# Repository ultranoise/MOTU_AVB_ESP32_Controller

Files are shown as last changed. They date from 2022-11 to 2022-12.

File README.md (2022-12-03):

# MOTU_AVB_ESP32_Controller
Building a simple volume controller with a ESP32 for MOTU AVB audio interfaces. Part of the [Ottosonics](https://tamlab.kunstuni-linz.at/projects/ottosonics/) project . 

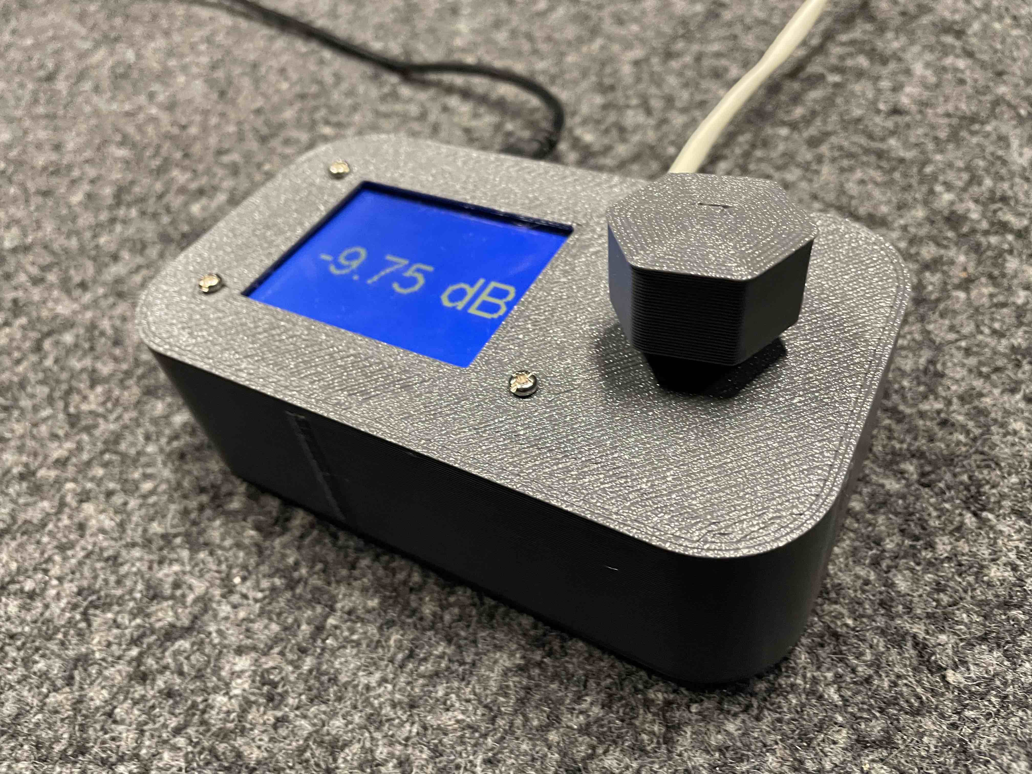
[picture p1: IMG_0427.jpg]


MOTU AVB interfaces have a particular method for receiving HTTP POST messages. First read the MOTU API Reference: 

https://cdn-data.motu.com/downloads/audio/AVB/docs/OSC%20Quick%20Reference.pdf

The principle to GET and POST with MOTU AVB interfaces is rather simple with cURL:

* get the datastore: ``` curl http://192.168.0.5/datastore ``` (use the IP of your interface here)

* read value of mic1 trim: ``` curl http://192.168.0.5/datastore/ext/ibank/0/ch/0/trim ```

* set value of mic1 trim: ``` curl --data 'json={"value":"45"}' http://192.168.0.5/datastore/ext/ibank/0/ch/0/trim ```

* set mixer fader 0 (ch1) value: ``` curl --data 'json={"value":"0.7"}' http://192.168.0.5/datastore/mix/chan/0/matrix/fader ```

* set mixer fader 1 (ch2) value: ``` curl --data 'json={"value":"0.7"}' http://192.168.0.5/datastore/mix/chan/1/matrix/fader ```

* set mixer fader 1 and fader 2 at the same time: ``` curl --data 'json={"0/matrix/fader":"0.2","1/matrix/fader":"0.1"}' http://192.168.0.5/datastore/mix/chan/ ```

# Hardware

We used a ESP32 with ethernet by [Olimex](https://www.olimex.com/Products/IoT/ESP32/ESP32-GATEWAY/open-source-hardware) and a [SPI TFT display](https://www.amazon.de/gp/product/B07YTWRZGR/ref=ppx_yo_dt_b_asin_title_o06_s01?ie=UTF8&psc=1) that we connected as follows:
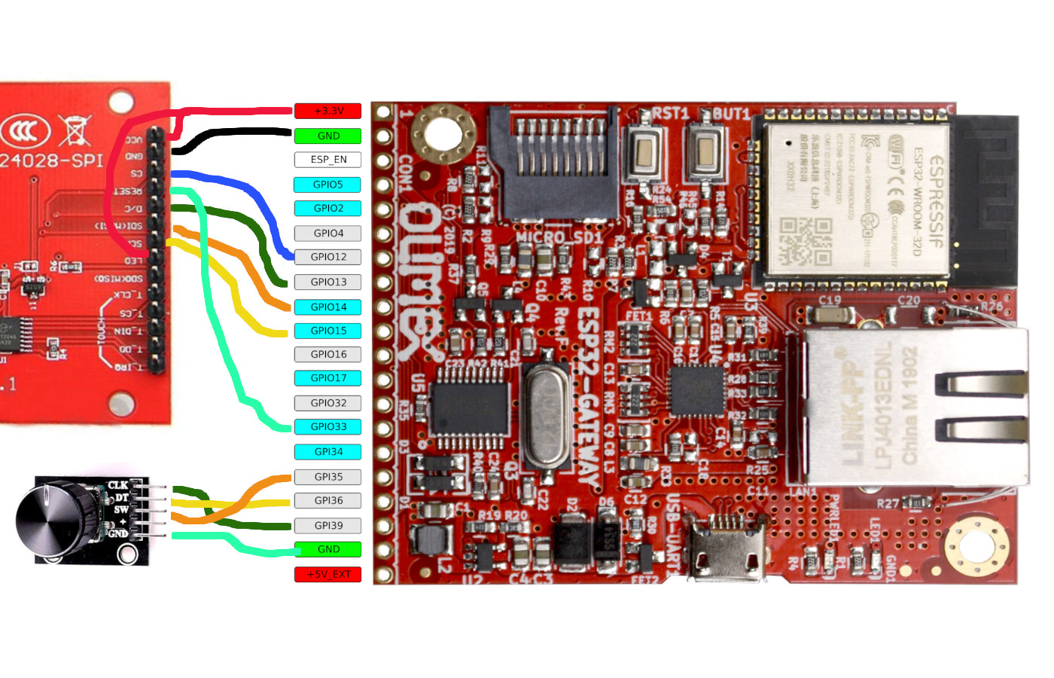
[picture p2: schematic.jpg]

Please note that a WLAN version of this code could be easily implemented with the same board (call wlan functions instead of ethernet). 

# Code

* If you want to download our solution please go to the source folder of this repository

* With our ESP32, the following code can be used to read the datastore:

```
#define ETH_CLK_MODE ETH_CLOCK_GPIO17_OUT
#define ETH_PHY_POWER 5
#include <ETH.h>
#include <HTTPClient.h>

#include <Arduino.h>

#define USE_SERIAL Serial

static bool eth_connected = false;

#include <WiFi.h>
#include <WiFiMulti.h>

WiFiMulti wifiMulti;

void WiFiEvent(WiFiEvent_t event)
{
  switch (event) {
    case ARDUINO_EVENT_ETH_START:
      USE_SERIAL.println("ETH Started");
      //set eth hostname here
      ETH.setHostname("esp32-ethernet");
      break;
    case ARDUINO_EVENT_ETH_CONNECTED:
      USE_SERIAL.println("ETH Connected");
      //eth_connected = true;
      break;
    case ARDUINO_EVENT_ETH_GOT_IP:
      USE_SERIAL.print("ETH MAC: ");
      USE_SERIAL.print(ETH.macAddress());
      USE_SERIAL.print(", IPv4: ");
      USE_SERIAL.print(ETH.localIP());
      if (ETH.fullDuplex()) {
        USE_SERIAL.print(", FULL_DUPLEX");
      }
      USE_SERIAL.print(", ");
      USE_SERIAL.print(ETH.linkSpeed());
      USE_SERIAL.println("Mbps");
      eth_connected = true;
      break;
    case ARDUINO_EVENT_ETH_DISCONNECTED:
      USE_SERIAL.println("ETH Disconnected");
      eth_connected = false;
      break;
    case ARDUINO_EVENT_ETH_STOP:
      USE_SERIAL.println("ETH Stopped");
      eth_connected = false;
      break;
    default:
      break;
  }
}

void testClient(const char * host, uint16_t port)
{
  USE_SERIAL.print("\nconnecting to ");
  USE_SERIAL.println(host);

  WiFiClient client;
  if (!client.connect(host, port)) {
    USE_SERIAL.println("connection failed");
    return;
  }
  client.printf("GET / HTTP/1.1\r\nHost: %s\r\n\r\n", host);
  while (client.connected() && !client.available());
  while (client.available()) {
    USE_SERIAL.write(client.read());
  }

  USE_SERIAL.println("closing connection\n");
  client.stop();
}

void testAvb(const char * host, uint16_t port)
{
  HTTPClient http;

        USE_SERIAL.print("[HTTP] begin...\n");
        // configure traged server and url
        http.begin("http://192.168.0.5/datastore/"); //HTTP
        
        USE_SERIAL.print("[HTTP] GET...\n");
        // start connection and send HTTP header
        int httpCode = http.GET();

        // httpCode will be negative on error
        if(httpCode > 0) {
            // HTTP header has been send and Server response header has been handled
            USE_SERIAL.printf("[HTTP] GET... code: %d\n", httpCode);

            // file found at server
            if(httpCode == HTTP_CODE_OK) {
                String payload = http.getString();
                USE_SERIAL.println(payload);
            }
        } else {
            USE_SERIAL.printf("[HTTP] GET... failed, error: %s\n", http.errorToString(httpCode).c_str());
        }

        http.end();
}

void setup()
{
  USE_SERIAL.begin(115200);
  WiFi.onEvent(WiFiEvent);
  ETH.begin();
}

void loop()
{
  if (eth_connected) {
    testAvb("google.com", 80);
  }
  delay(10000);
}
```

* The issues begin when you try to POST messages. The logic of posting with JSON encoding doesn't work. If you typically use the following code you will get an error:

```

void postDataToServer() {

    HTTPClient http;

    http.begin("http://192.168.0.5/datastore/ext/obank/2/ch/0/name");
    
    http.addHeader("Content-Type", "application/json");
    
    int httpResponseCode = http.POST("{\"value\":\"My favorite channel\"}");
    
    if (httpResponseCode > 0) {

      String response = http.getString();

      Serial.println(httpResponseCode);
      Serial.println(response);

    } else {

      Serial.print("Error on sending PUT Request: ");
      Serial.println(httpResponseCode);

    }

    http.end();
     
}
```

you get a (-5) or (-1) error:

```
ETH Connected
 POSTing to Server...
-5

```
 
So clearly there is a difference in how headers or formatting are set. I used the online service httpbin.org to debug the messages. Basically httpbin.org replied me a copy of what we have to send.  
  
This is what you get if you use the cURL command which works with the MOTU:

```
curl --data 'json={"value":"My favorite channel"}' https://httpbin.org/post  
{
  "args": {}, 
  "data": "", 
  "files": {}, 
  "form": {
    "json": "{\"value\":\"My favorite channel\"}"
  }, 
  "headers": {
    "Accept": "*/*", 
    "Content-Length": "36", 
    "Content-Type": "application/x-www-form-urlencoded", 
    "Host": "httpbin.org", 
    "User-Agent": "curl/7.64.1", 
    "X-Amzn-Trace-Id": "Root=1-62a2ec58-01489dc01c52f8201f03eccb"
  }, 
  "json": null, 
  "origin": "188.23.136.201", 
  "url": "https://httpbin.org/post"
}
```

However, with the previous Arduino code (which doesn't work with the MOTU interface)

```
200
{
  "args": {}, 
  "data": "{\"value\":\"My favorite channel\"}", 
  "files": {}, 
  "form": {}, 
  "headers": {
    "Accept-Encoding": "identity;q=1,chunked;q=0.1,*;q=0", 
    "Content-Length": "31", 
    "Content-Type": "application/json", 
    "Host": "httpbin.org", 
    "User-Agent": "ESP32HTTPClient", 
    "X-Amzn-Trace-Id": "Root=1-62a2e98e-0825a5fe531b2c493b88287d"
  }, 
  "json": {
    "value": "My favorite channel"
  }, 
  "origin": "188.23.136.201", 
  "url": "https://httpbin.org/post"
}

```

Ergo-> there are quite noticeable differences!!

If we use the same arduino code with a different header ("application/x-www-form-urlencoded") instead of (application/json")

```
//http.addHeader("Content-Type", "application/json");
http.addHeader("Content-Type", "application/x-www-form-urlencoded");
```

We get 

```
200
{
  "args": {}, 
  "data": "", 
  "files": {}, 
  "form": {
    "{\"value\":\"My favorite channel\"}": ""
  }, 
  "headers": {
    "Accept-Encoding": "identity;q=1,chunked;q=0.1,*;q=0", 
    "Content-Length": "31", 
    "Content-Type": "application/x-www-form-urlencoded", 
    "Host": "httpbin.org", 
    "User-Agent": "ESP32HTTPClient", 
    "X-Amzn-Trace-Id": "Root=1-62a2ee48-42acf6c158c472cf4e3d67b8"
  }, 
  "json": null, 
  "origin": "188.23.136.201", 
  "url": "https://httpbin.org/post"
}
```

Which looks better, but to accommondate the format that the MOTU interface expects ( json={} ) this is the final code which finally works:

```
void postDataToServerTwo() {
    HTTPClient http;

    http.begin("http://192.168.0.5/datastore/mix/chan/0/matrix/fader"); 
    
    http.addHeader("Content-Type", "application/x-www-form-urlencoded");
    
    int httpResponseCode = http.POST("json={\"value\":\"0.7\"}"); 

    if (httpResponseCode > 0) {

      String response = http.getString();

      Serial.println(httpResponseCode);
      Serial.println(response);

    } else {

      Serial.print("Error on sending PUT Request: ");
      Serial.println(httpResponseCode);

    }

    http.end();
}
```

This simple produces a "204" response and moves the fader!

You can take a look at a complete example in the src folder.

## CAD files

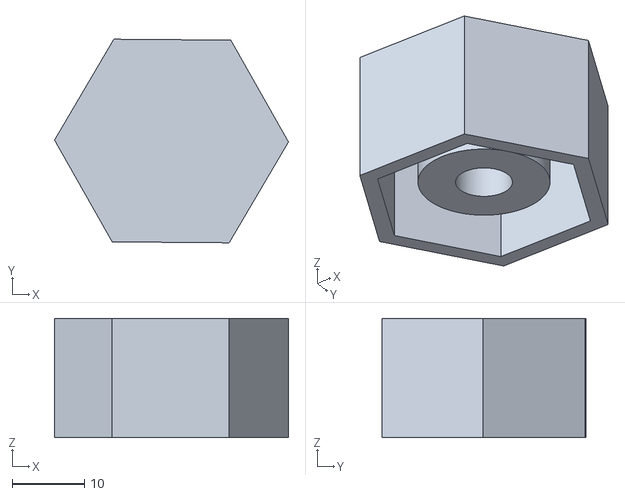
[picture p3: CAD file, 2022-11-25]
3dprint/OTTOsonics volume control knob.stl
32.3 x 28.1 x 16.5

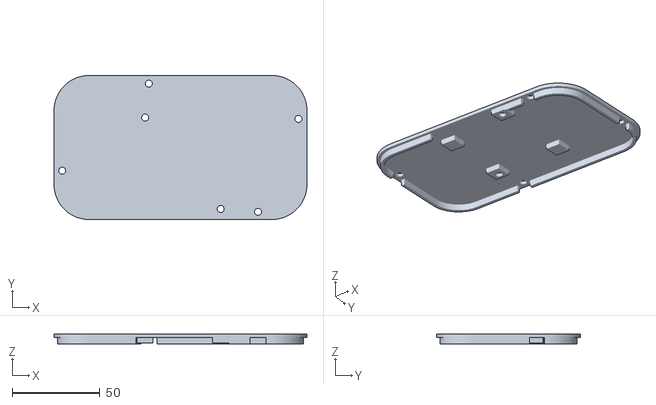
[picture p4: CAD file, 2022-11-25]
3dprint/OTTOsonics volume control lid.stl
144.0 x 82.0 x 5.60

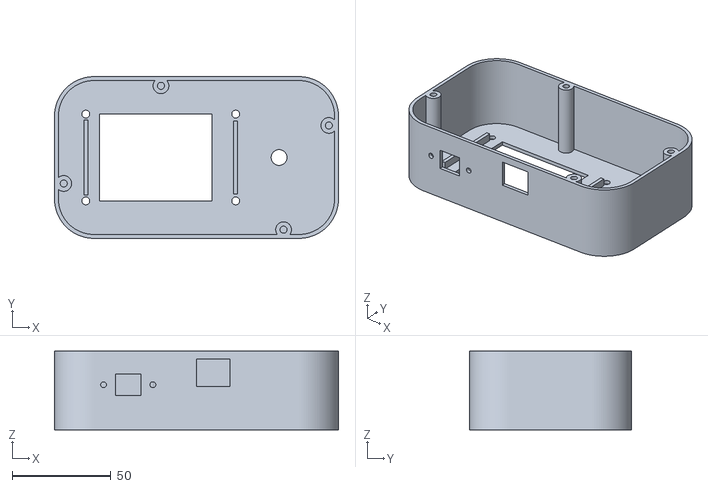
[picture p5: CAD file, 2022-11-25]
3dprint/OTTOsonics volume control body.stl
144.0 x 82.0 x 40.0

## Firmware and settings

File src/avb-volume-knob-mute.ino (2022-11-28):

///////////////////////////////////////
// AVB VOLUME KNOB
// PRESS KNOB FOR PANIC MODE (-24DB)
// enrique.tomas@kunstuni-linz.at 2022
// use this code at your own risk,
// no responsabilities granted. 
//////////////////////////////////////

#include "SPI.h"
#include "TFT_eSPI.h"
#include "Free_Fonts.h" // Include the header file attached to this sketch
// FreeFonts. Include access to the 48 Adafruit_GFX free fonts FF1 to FF48 and custom fonts
#define LOAD_GFXFF

#define ETH_CLK_MODE ETH_CLOCK_GPIO17_OUT
#define ETH_PHY_POWER 5
#include <ETH.h>
#include <HTTPClient.h>
#include <Arduino.h>
#include <ESP32Encoder.h>
#include <ArduinoJson.h>
#include <WiFi.h>
#include <WiFiMulti.h>

#define USE_SERIAL Serial
static bool eth_connected = false;

WiFiMulti wifiMulti;

const char* server = "http://192.168.0.101/datastore/mix/chan/0/matrix/fader";


//Sensor vars
ESP32Encoder encoder; //encoder variable
int encoderValue = 0;
int encoderValue_past = 0;
int encoderIncrement = 0;
int encoderIncrement_past;
int pushButton = 35; //push button in the encoder
int pushValue = 1;
int pushValue_past = 0;
bool newIncValue = false;

//fader values etc
float faderVolume;
float dbVolume;
float incVol;
bool firstConnection = true;
bool in_connection = true;
bool init_end = false;

// Use hardware SPI
TFT_eSPI tft = TFT_eSPI();

unsigned long drawTime = 0;
int xpos, ypos;

String devices_ip[10];
String uids[10];
String IPdevices2control[10];
int counter_device2control = 0;
int devices_number = 0;
int selected_device = 0;

int studio = 2;  //0 -> tamlab, 1->alter bauhof, 2-> tamlab second rack

//controlling various faders
//we have to build 'json={"0/matrix/fader":"0.2","1/matrix/fader":"0.1"}' http://192.168.0.5/datastore/mix/chan/
    
StaticJsonDocument<400> doc_mul;

void WiFiEvent(WiFiEvent_t event)
{
  switch (event) {
    case ARDUINO_EVENT_ETH_START:
      USE_SERIAL.println("ETH Started");
      //set eth hostname here
      ETH.setHostname("esp32-ethernet");
      break;
    case ARDUINO_EVENT_ETH_CONNECTED:
      USE_SERIAL.println("ETH Connected");
      //eth_connected = true;
      break;
    case ARDUINO_EVENT_ETH_GOT_IP:
      USE_SERIAL.print("ETH MAC: ");
      USE_SERIAL.print(ETH.macAddress());
      USE_SERIAL.print(", IPv4: ");
      USE_SERIAL.print(ETH.localIP());
      if (ETH.fullDuplex()) {
        USE_SERIAL.print(", FULL_DUPLEX");
      }
      USE_SERIAL.print(", ");
      USE_SERIAL.print(ETH.linkSpeed());
      USE_SERIAL.println("Mbps");
      eth_connected = true;
      break;
    case ARDUINO_EVENT_ETH_DISCONNECTED:
      USE_SERIAL.println("ETH Disconnected");
      eth_connected = false;
      break;
    case ARDUINO_EVENT_ETH_STOP:
      USE_SERIAL.println("ETH Stopped");
      eth_connected = false;
      break;
    default:
      break;
  }
}




float retrieveDevices(String ip_devices)
{
  HTTPClient http;

        USE_SERIAL.println(" ");
        USE_SERIAL.print("retrieving UUID information...\n");
        // configure traged server and url
        
        http.begin(ip_devices + "/datastore/avb/devs"); 

        //USE_SERIAL.print("[HTTP] GET...\n");
        // start connection and send HTTP header
        int httpCode = http.GET();

        // httpCode will be negative on error
        if(httpCode > 0) {
            // HTTP header has been send and Server response header has been handled
            //USE_SERIAL.printf("[HTTP] GET... code: %d\n", httpCode);

            // file found at server
            if(httpCode == HTTP_CODE_OK) {
                String payload = http.getString();
                
                //USE_SERIAL.println("payload");
                //USE_SERIAL.println(payload);

                //fader payload is a String like {"value":0.7}
                //from where we have to extract the value
                             
                DynamicJsonDocument doc(200);
                DeserializationError error =deserializeJson(doc, payload);

                // Test if parsing succeeds.
                if (error) {
                  
                  USE_SERIAL.print(F("deserializeJson() failed: "));
                  USE_SERIAL.println(error.f_str());
                  http.end();
                  return -1.0;
                } else {
                  String f = doc["value"];
                  USE_SERIAL.println("UID values");
                  USE_SERIAL.println(f);

                  int l = f.length();  //length of the string obtained e.g. 0001f2fffe008f93:0001f2fffe00f7c9
                  //USE_SERIAL.println(l);
                  
                  int n = l / 16; //each device is 16 characters, separated by :, n is the number of devices
                  USE_SERIAL.print("number of devices: ");
                  USE_SERIAL.println(n);

                  //necessary variables to extract each uid and ip:
                  
                  HTTPClient http2;

                  String uid_ip;
                  String uid_path;
                  
                  //RETRIEVE IPS OF EACH DEVICE
                  USE_SERIAL.println(" ");
                  USE_SERIAL.print("retrieving IP information of each device...\n");
                  
                  for(int i=0;i<n;i++) {
                    uids[i] = f.substring(0 + i*17, 16 + i*17);  

                    USE_SERIAL.print("Device: ");
                    USE_SERIAL.println(uids[i]);   
                    USE_SERIAL.println("index: " + i);
                       
                    // configure traged server and url
                    uid_path = ip_devices + "/datastore/avb/" + uids[i] + "/url";
                          
                    //USE_SERIAL.println(uid_path);
                    http2.begin(uid_path); 
                  
                    
                    // start connection and send HTTP header
                    httpCode = http2.GET();
                  
                    // httpCode will be negative on error
                    if(httpCode > 0) {
                                          
                      // file found at server
                      if(httpCode == HTTP_CODE_OK) {
                        
                          String payload2 = http2.getString();
                                  
                          //USE_SERIAL.println("payload");
                          USE_SERIAL.println(payload2);
                  
                          //fader payload is a String like {"value":0.7}
                          //from where we have to extract the value
                          DynamicJsonDocument doc2(200);
                          DeserializationError error2 = deserializeJson(doc2, payload2);
                  
                           // Test if parsing succeeds.
                           if (error2) {
                              USE_SERIAL.print(F("deserializeJson() failed: "));
                              USE_SERIAL.println(error2.f_str());
                              http2.end();
                              return -1.0;
                              
                            } else {
                              String ff = doc2["value"];
                              devices_ip[i] = ff;
                              devices_number = devices_number + 1;
                              USE_SERIAL.print("IP value: ");
                              USE_SERIAL.println(ff); 
                              USE_SERIAL.println("index: " + i);
                            }
                                  
                                  
                        }
                      } else {
                              USE_SERIAL.printf("[HTTP] GET... failed, error: %s\n", http.errorToString(httpCode).c_str());
                              http2.end();
                              return -1.0;
                          }

                          http2.end();
                                  
                    //END OF IP RETRIEVEMENT
                    
                  }//END OF FOR 
          
                  
                  http.end();
                  return 1.0;
                }
                
                
            }
        } else {
            USE_SERIAL.printf("[HTTP] GET... failed, error: %s\n", http.errorToString(httpCode).c_str());
            http.end();
            return -1.0;
        }
        
        
}


float getTrimValue() {
  HTTPClient http;

  //USE_SERIAL.print("[HTTP] begin...\n");
  // configure traged server and url
  String path = "http://" + IPdevices2control[0] + "/datastore/ext/obank/0/ch/0/trim";  //try with the first obank
  USE_SERIAL.println("retrieving fader values from the following path: ");
  USE_SERIAL.println(path);
  
  http.begin(path); 
  

  //USE_SERIAL.print("[HTTP] GET...\n");
  // start connection and send HTTP header
  int httpCode = http.GET();

  // httpCode will be negative on error
  if(httpCode > 0) {
      // HTTP header has been send and Server response header has been handled
      //USE_SERIAL.printf("[HTTP] GET... code: %d\n", httpCode);

      // file found at server
      if(httpCode == HTTP_CODE_OK) {
          String payload = http.getString();
          
          USE_SERIAL.println("payload");
          USE_SERIAL.println(payload);

          //fader payload is a String like {"value":0.7}
          //from where we have to extract the value
          
          
          DynamicJsonDocument doc(200);
          DeserializationError error =deserializeJson(doc, payload);

          // Test if parsing succeeds.
          if (error) {
            
            USE_SERIAL.print(F("deserializeJson() failed: "));
            USE_SERIAL.println(error.f_str());
            http.end();
            return -1.0;
          } else {
            float f = doc["value"];
            USE_SERIAL.println("extracted value");
            USE_SERIAL.println(f);
            http.end();
            return f;
          }
          
          
      }
  } else {
      USE_SERIAL.printf("[HTTP] GET... failed, error: %s\n", http.errorToString(httpCode).c_str());
      http.end();
      return -1.0;
  }

               
}


float getFaderValue() {
  HTTPClient http;

        //USE_SERIAL.print("[HTTP] begin...\n");
        // configure traged server and url
        String path = "http://" + devices_ip[selected_device] + "/datastore/mix/chan/0/matrix/fader";
        http.begin(path); 
        //http.begin("http://192.168.0.101/datastore/mix/chan/0/matrix/fader"); 

        //USE_SERIAL.print("[HTTP] GET...\n");
        // start connection and send HTTP header
        int httpCode = http.GET();

        // httpCode will be negative on error
        if(httpCode > 0) {
            // HTTP header has been send and Server response header has been handled
            //USE_SERIAL.printf("[HTTP] GET... code: %d\n", httpCode);

            // file found at server
            if(httpCode == HTTP_CODE_OK) {
                String payload = http.getString();
                
                //USE_SERIAL.println("payload");
                //USE_SERIAL.println(payload);

                //fader payload is a String like {"value":0.7}
                //from where we have to extract the value
                
                
                DynamicJsonDocument doc(200);
                DeserializationError error =deserializeJson(doc, payload);

                // Test if parsing succeeds.
                if (error) {
                  
                  USE_SERIAL.print(F("deserializeJson() failed: "));
                  USE_SERIAL.println(error.f_str());
                  http.end();
                  return -1.0;
                } else {
                  float f = doc["value"];
                  //USE_SERIAL.println("extracted value");
                  //USE_SERIAL.println(f);
                  http.end();
                  return f;
                }
                
                
            }
        } else {
            USE_SERIAL.printf("[HTTP] GET... failed, error: %s\n", http.errorToString(httpCode).c_str());
            http.end();
            return -1.0;
        }

        
        
}


void postDataToServerJSON(float vol) {
    
    StaticJsonDocument<200> doc;
    doc["value"] = vol;
    
    //Serial.println("deserialized doc" );
    //serializeJson(doc, Serial);  // Generate the minified JSON and send it to the Serial port.
    // The above should print:
    // {"value":0.3}

    // Start a new line
    //Serial.println();
    
    String s;
    serializeJson(doc, s); 
    
    //Serial.println("string s" );
    //Serial.println(s);
    
    HTTPClient http;

    //path to one fader
    http.begin("http://192.168.0.101/datastore/mix/chan/0/matrix/fader");  
    
    //http.addHeader("Content-Type", "application/json");
    http.addHeader("Content-Type", "application/x-www-form-urlencoded");
    
    
    //int httpResponseCode = http.POST("json={\"value\":\"My favorite channel\"}"); (this is ok)
    //int httpResponseCode = http.POST("json={\"value\":\"0.7\"}"); //(this is ok)
    int httpResponseCode = http.POST("json=" + s); 
     
    if (httpResponseCode > 0) {

      String response = http.getString();

      //Serial.println(httpResponseCode);
      //Serial.println(response);

    } else {

      Serial.print("Error on sending PUT Request: ");
      Serial.println(httpResponseCode);

    }

    http.end();

}


void postDataToServerJSONmultipleIP(float vol, int device_nr, String ipNumber) {

    //TO ACT ON THE TRIMMS : {"ext/obank/0/ch/0/trim":-18}  -> but this has to be done for each of the devices
    
    
    String s;
    serializeJson(doc_mul, s); 
    
    //Serial.println("string s" );
    //Serial.println(s);
    
    HTTPClient http;
    //http.begin("http://" + devices_ip[device_nr] + "/datastore/");  //root for adding the doc[]
    
    //http.begin("http://192.168.0.102/datastore/");  //root for adding the doc[]
    
    http.begin("http://" + ipNumber + "/datastore/");  //root for adding the doc[]
    
    http.addHeader("Content-Type", "application/x-www-form-urlencoded");
      
    int httpResponseCode = http.POST("json=" + s); 
     
    if (httpResponseCode > 0) {

      String response = http.getString();

      //Serial.println(httpResponseCode);
      //Serial.println(response);

    } else {

      Serial.print("Error on sending PUT Request: ");
      Serial.println(httpResponseCode);

    }

    http.end();

}



void setup(void) {

  USE_SERIAL.begin(115200);
  //Serial.begin(115200);
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
void loop() {


  if (eth_connected) {
        
        if(firstConnection) {
          
          //clear screen 
          
          tft.fillScreen(TFT_NAVY);
          //tft.setFreeFont(FSB24);
          tft.drawString("Connecting...", xpos, ypos + 100, GFXFF);
          delay(2000);
          tft.fillScreen(TFT_NAVY);
          
          
          while(init_end == false){
            //clear screen 
            ypos = 20;
            //tft.fillScreen(TFT_BLACK);
            
            //tft.setFreeFont(FSB9);
            //tft.setTextSize(2); 
            tft.setFreeFont(FF10);
            tft.drawString("Available devices:", xpos, ypos + 15, GFXFF);
            for(int i=0;i<devices_number;i++){
              tft.drawString(String(i) + ": " + devices_ip[i], xpos, ypos + 15 + 20*(i+1), GFXFF);
            }
           
            //tft.setFreeFont(FSB9);
            tft.drawString("Press Encoder", xpos, 25+ ypos + 15*(devices_number+3), GFXFF);
            tft.drawString("to continue", xpos, 25+ ypos + 15*(devices_number+3) + 20, GFXFF);
            
            //tft.drawString("111", xpos, ypos + 14*(devices_number+2), GFXFF);

            tft.setFreeFont(FF18);
            encoderValue = encoder.getCount(); //encoder position absolute
            
            //let the user push the button to continue
            pushValue = digitalRead(pushButton); //push button in the encoder
            if(pushValue == 0) {
              init_end = true;   //change the flag to continue
              tft.fillScreen(TFT_NAVY);
              tft.drawString("initializing...", xpos, 25+ ypos + 15*(devices_number+3), GFXFF);
             } 
            
            //USE_SERIAL.print("push button ");
            //USE_SERIAL.println(pushValue);
    
            
            //check if it is different
            
            delay(300);
            
          } //end 

          

          //we have selected the device now, we can see the fader values and change them

          
          //retrieve fader value at the beginning
          USE_SERIAL.println(" ");
          USE_SERIAL.print("Retrieving trim values from interface... ");

         faderVolume = getTrimValue();  //uses the ip of selected device--> returns value in dB already
                           
         //dbVolume = 20*log10(faderVolume);  //transform to dB
          
          //display in tft
          tft.fillScreen(TFT_NAVY);
          //tft.setFreeFont(FSB24);
          tft.setTextSize(3); 
          tft.setFreeFont(FF18);
          tft.drawString(String(faderVolume), xpos - 50, 100, GFXFF);  //tft.drawString(String(dbVolume), xpos, 100, GFXFF);
          tft.drawString("dB", xpos + 100, 100, GFXFF);
                                  
          firstConnection = false;
          USE_SERIAL.println("Ready!");
          delay(3000);
          //initial encoder value is 0
          
        } //end of if(first connection)
        else {
                //encoder reading

                pushValue = digitalRead(pushButton); //push button in the encoder
                if(pushValue == 0){
                  faderVolume = -24.0;

                  //quiza crear aqui los doc de json y no en cada loop
                  doc_mul["ext/obank/0/ch/0/trim"] = faderVolume;
                  doc_mul["ext/obank/0/ch/1/trim"] = faderVolume;
                  doc_mul["ext/obank/0/ch/2/trim"] = faderVolume;
                  doc_mul["ext/obank/0/ch/3/trim"] = faderVolume;
                  doc_mul["ext/obank/0/ch/4/trim"] = faderVolume;
                  doc_mul["ext/obank/0/ch/5/trim"] = faderVolume;
                  doc_mul["ext/obank/0/ch/6/trim"] = faderVolume;
                  doc_mul["ext/obank/0/ch/7/trim"] = faderVolume;
                  doc_mul["ext/obank/0/ch/8/trim"] = faderVolume;
                  doc_mul["ext/obank/0/ch/9/trim"] = faderVolume;
                  doc_mul["ext/obank/0/ch/10/trim"] = faderVolume;
                  doc_mul["ext/obank/0/ch/11/trim"] = faderVolume;
                  doc_mul["ext/obank/0/ch/12/trim"] = faderVolume;
                  doc_mul["ext/obank/0/ch/13/trim"] = faderVolume;
                  doc_mul["ext/obank/0/ch/14/trim"] = faderVolume;
                  doc_mul["ext/obank/0/ch/15/trim"] = faderVolume;
                  doc_mul["ext/obank/0/ch/16/trim"] = faderVolume;
                  doc_mul["ext/obank/0/ch/17/trim"] = faderVolume;
                  doc_mul["ext/obank/0/ch/18/trim"] = faderVolume;
                  doc_mul["ext/obank/0/ch/19/trim"] = faderVolume;
                  doc_mul["ext/obank/0/ch/20/trim"] = faderVolume;
                  doc_mul["ext/obank/0/ch/21/trim"] = faderVolume;
                  doc_mul["ext/obank/0/ch/22/trim"] = faderVolume;
                  doc_mul["ext/obank/0/ch/23/trim"] = faderVolume;
                  
                  
           

                  for(int i=0;i<counter_device2control;i++) {
                    postDataToServerJSONmultipleIP(faderVolume, 0, IPdevices2control[i]); 
                  } 
                  

                  //dbVolume = (int((20*log10(faderVolume))*10))/10;  //transform to dB
                  //dbVolume = 20*log10(faderVolume);  //transform to dB
                  
                  /*
                  USE_SERIAL.println(" ");
                  USE_SERIAL.print("faderdB ");
                  USE_SERIAL.println(dbVolume);
                  USE_SERIAL.println(" ");
                */
                  
                  //display in tft
                  tft.setTextSize(3); 
                  tft.fillScreen(TFT_NAVY);
                  tft.setFreeFont(FF18);
                  //tft.setFreeFont(FSB24);
                  //tft.drawString(String(faderVolume), xpos, ypos, GFXFF);
                  tft.drawString(String(faderVolume), xpos - 50, 100, GFXFF);
                  tft.drawString("dB", xpos + 100, 100, GFXFF);
                  //ypos += tft.fontHeight(GFXFF);
                  delay(250);
                
                } else {
                  encoderValue = encoder.getCount(); //encoder position absolute
                 /*
                 USE_SERIAL.print("encoderValue ");
                 USE_SERIAL.println(encoderValue);
                 USE_SERIAL.print("encoderPastValue ");
                 USE_SERIAL.println(encoderValue_past);
                 */
                 //check if it is different
                if(encoderValue_past != encoderValue) {
        
                  encoderIncrement = encoderValue-encoderValue_past;  //this can be positive or negative
                  
                  //USE_SERIAL.print("enc increment ");
                  //USE_SERIAL.println(encoderIncrement);
                  
                  incVol =  0.5 * encoderIncrement/4;
                  //USE_SERIAL.print("inc vol ");
                  //USE_SERIAL.println(incVol);
                  faderVolume = faderVolume + incVol*2;
                  
                  if(faderVolume > 0) faderVolume = 0.0;
                  if(faderVolume < -24) faderVolume = -24.0;
                  
                  //USE_SERIAL.print("faderVolume ");
                  //USE_SERIAL.println(faderVolume);
                  encoderValue_past = encoderValue;
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
